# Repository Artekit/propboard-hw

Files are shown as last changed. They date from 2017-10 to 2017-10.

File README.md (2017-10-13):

# Artekit PropBoard Hardware

This repository contains hardware-related files for the [Artekit PropBoard](https://www.artekit.eu/products/devboards/propboard/).

(https://www.artekit.eu/products/devboards/propboard/)

## Documentation

* [Product page](https://www.artekit.eu/products/devboards/propboard/)
* [Manual & APIs](https://www.artekit.eu/doc/categories/propboard/)

## License

Released under the Creative Commons Attribution Share-Alike 3.0 License (http://creativecommons.org/licenses/by-sa/3.0)

Copyright (c) 2017 Artekit Labs.

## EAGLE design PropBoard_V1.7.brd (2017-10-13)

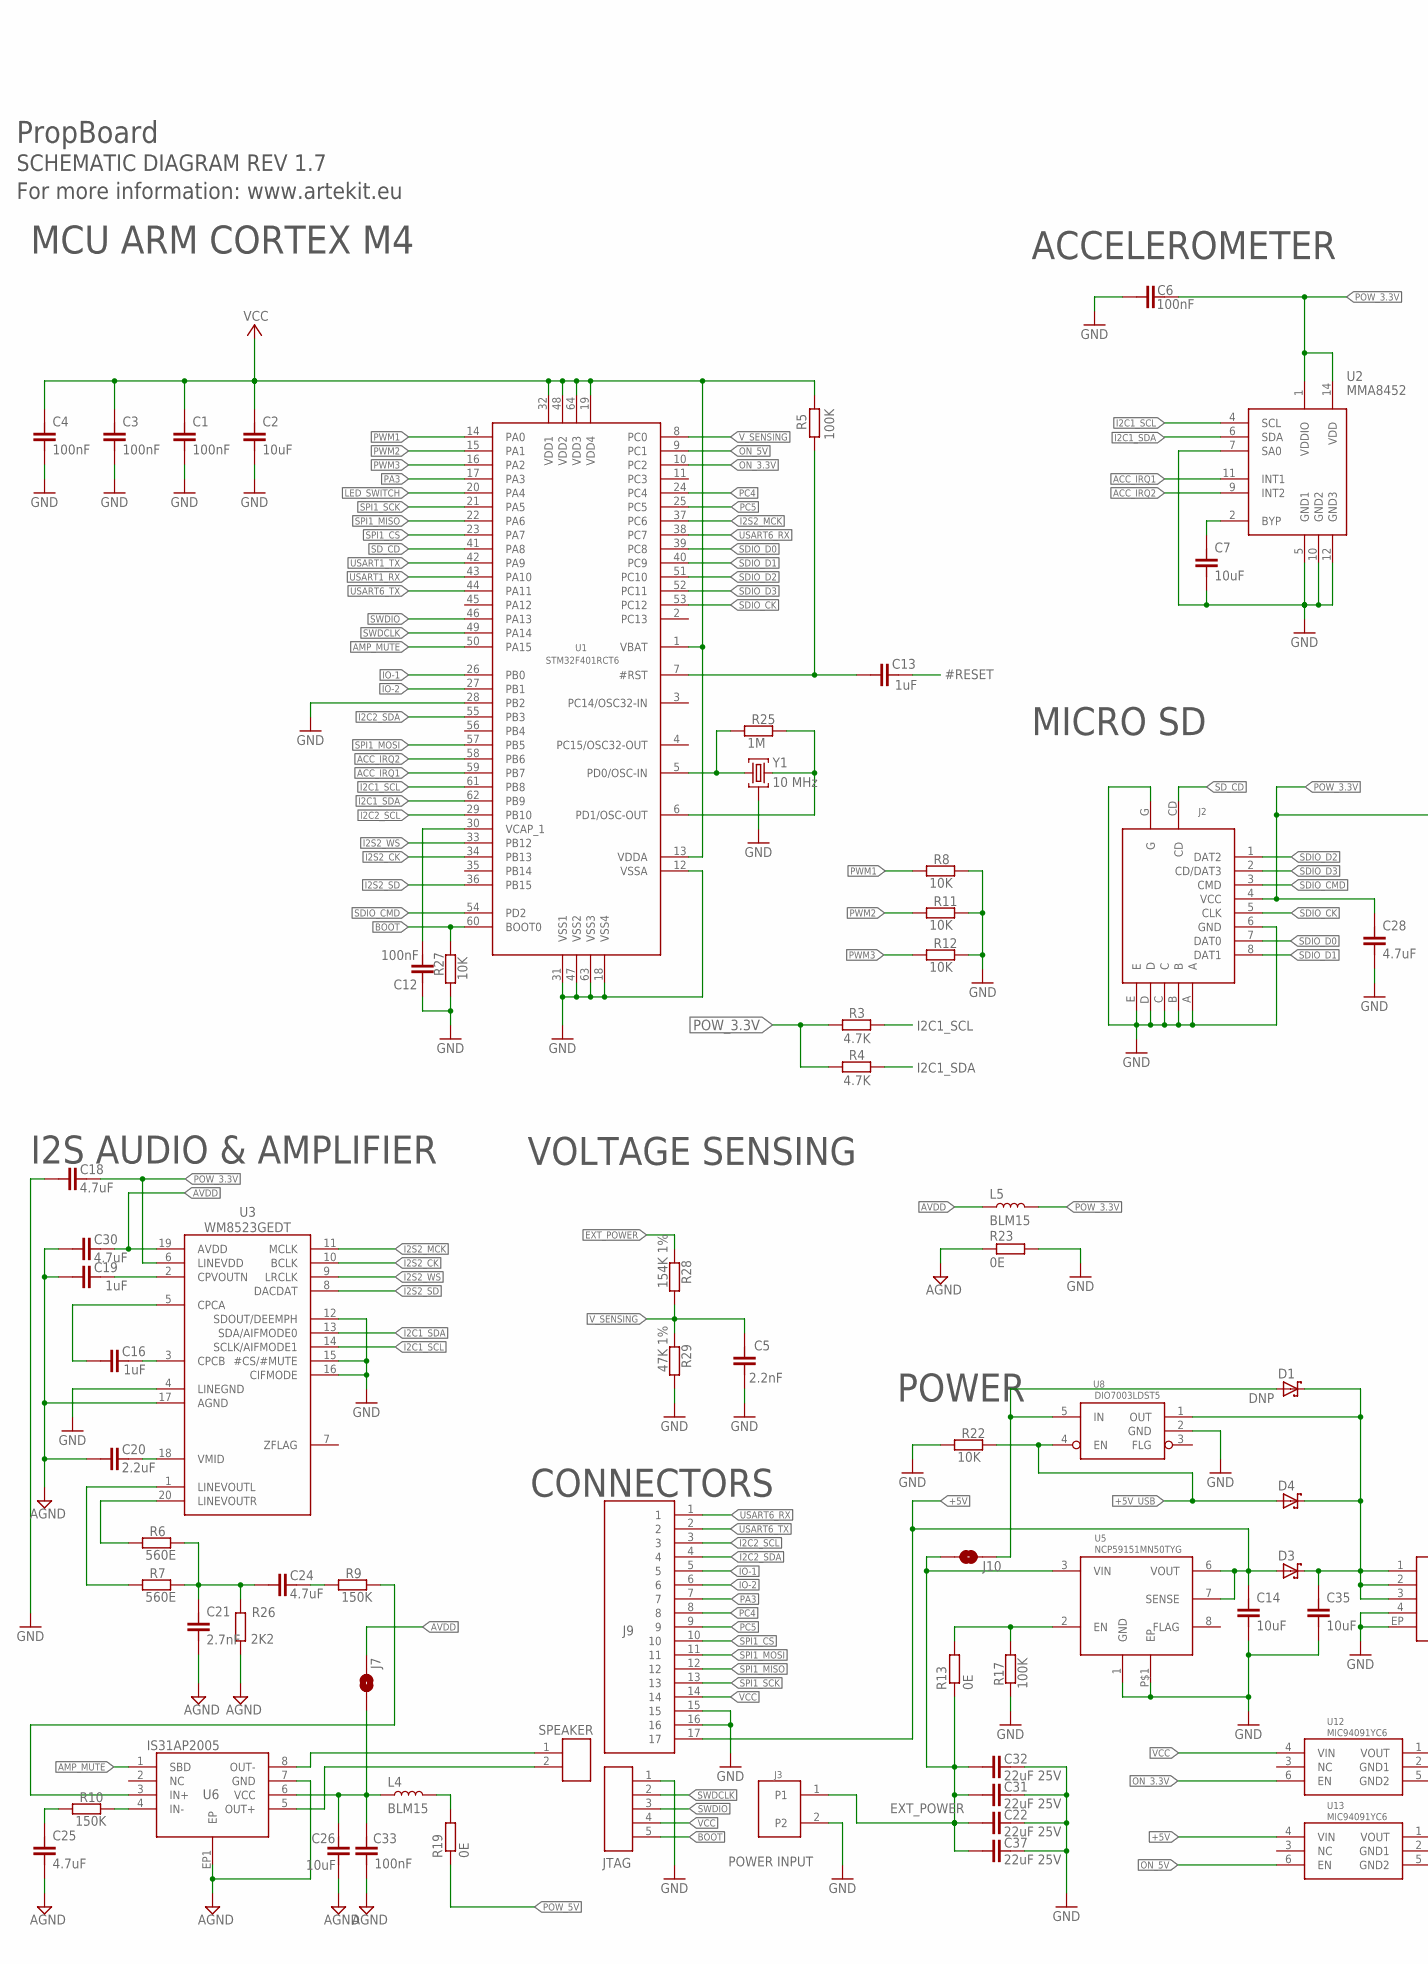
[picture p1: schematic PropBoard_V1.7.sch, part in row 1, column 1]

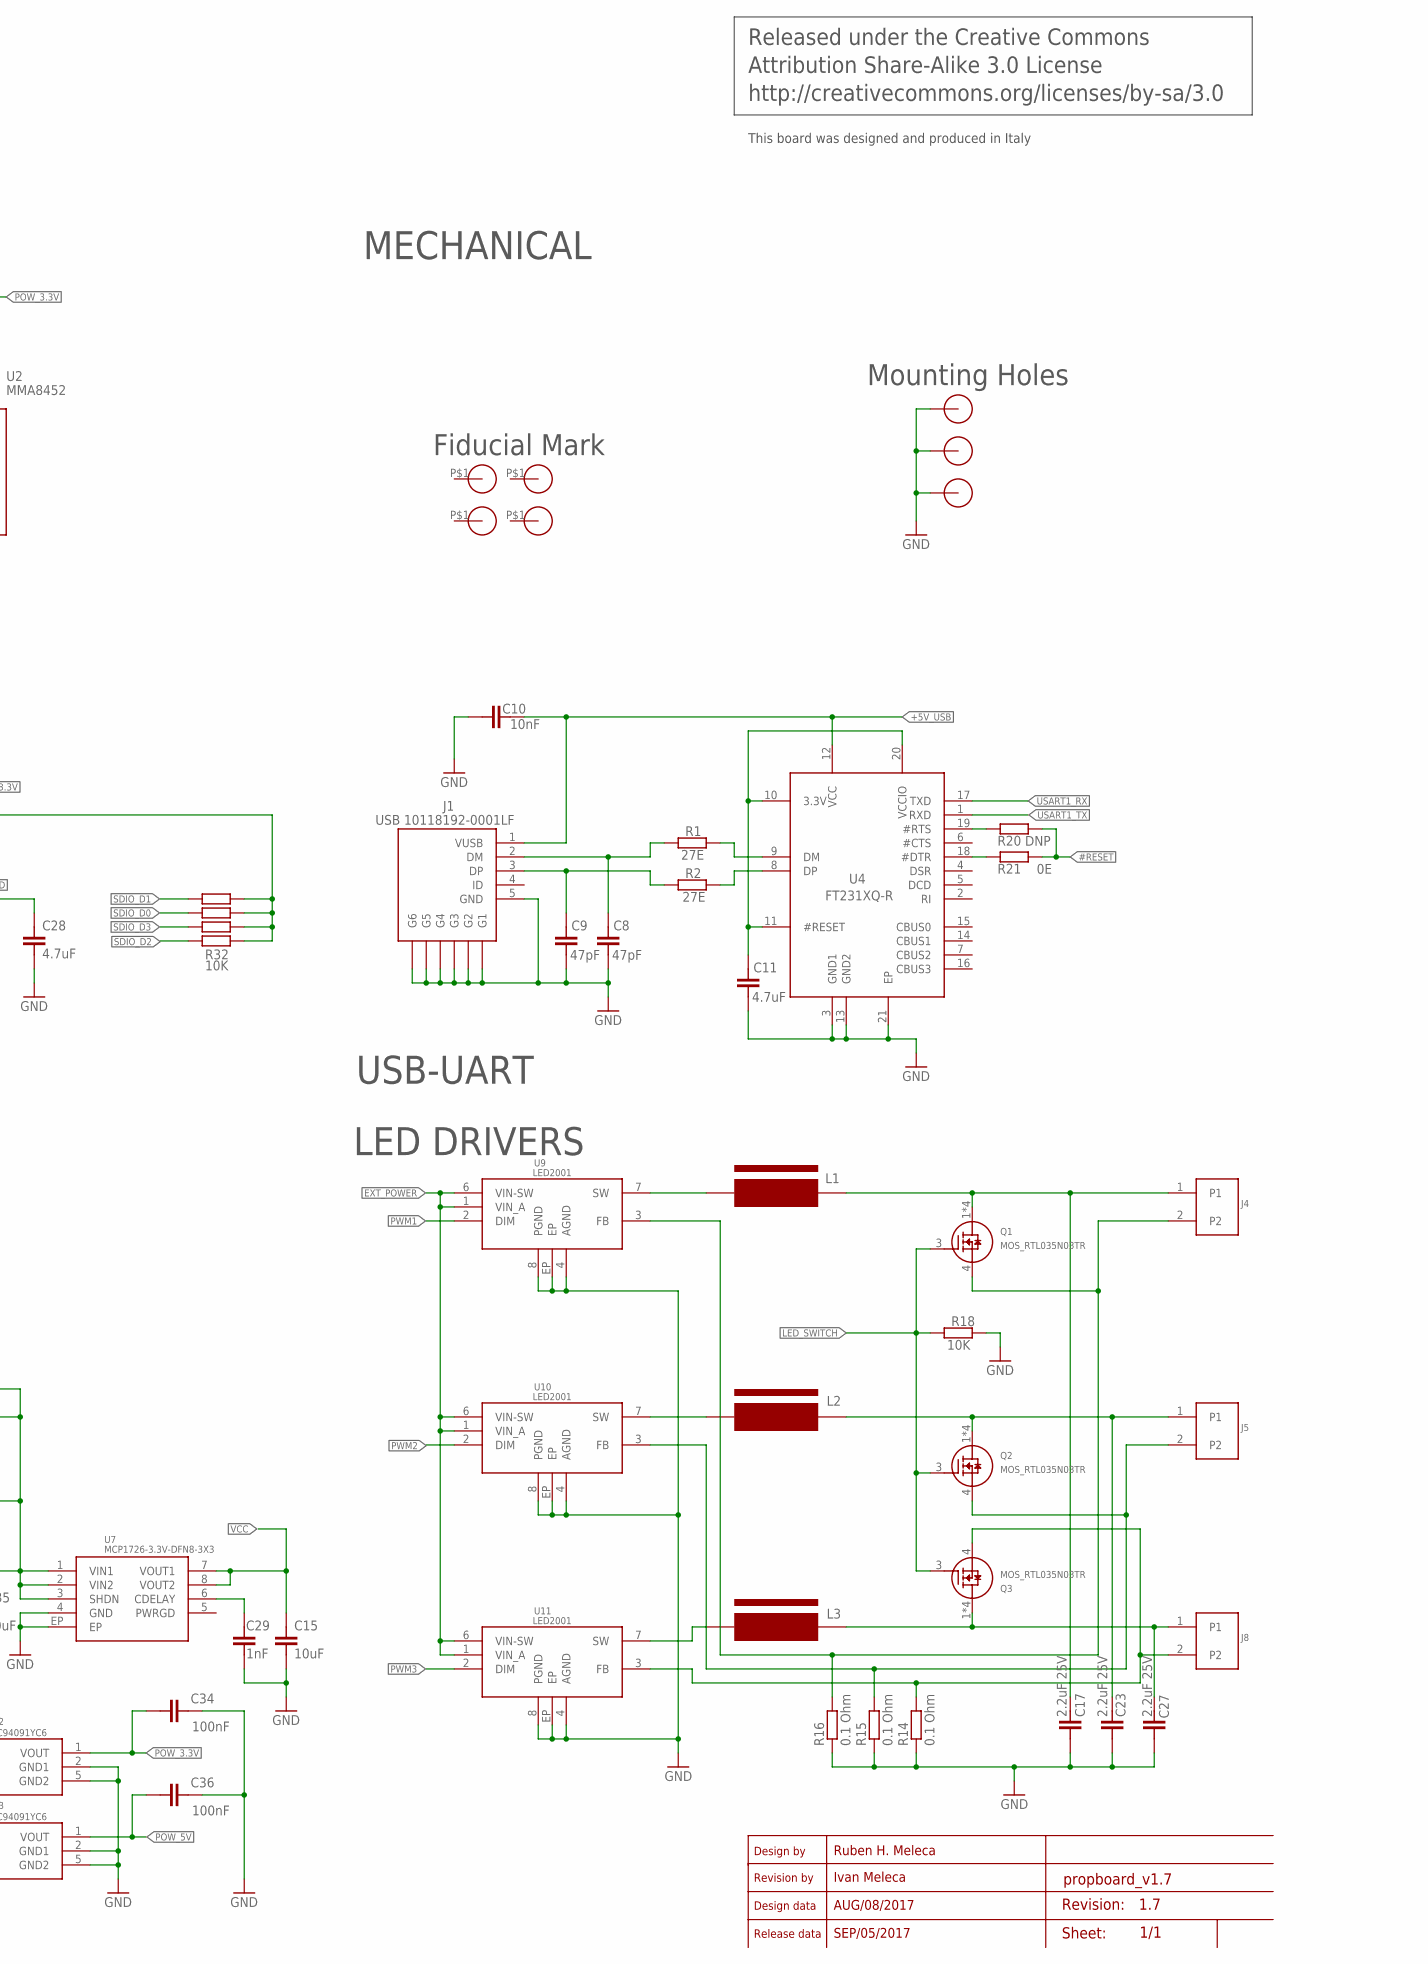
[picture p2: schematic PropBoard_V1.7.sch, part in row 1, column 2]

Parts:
C1, C3, C4, C6, C12, C33, C34, C36: 100nF; C0402
C2, C7, C14, C15, C26, C35: 10uF; C0402
C5: 2.2nF; C0402
C8, C9: 47pF; C0402
C10: 10nF; C0402
C11, C18, C24, C25, C28, C30: 4.7uF; C0402
C13, C19: 1uF; C0402
C16: 1uF; C0402-WIDE
C17, C23, C27: 2.2uF 25V; C0603
C20: 2.2uF; C0402
C21: 2.7nF; C0402
C22, C31, C32, C37: 22uF 25V; C0805
C29: 1nF; C0402
D1: DNP; SOD-323
D3, D4: BAT60; SOD-323
J1: USB 10118192-0001LF; CON-USB-MICRO-B-SMD
J2: MICRO-SD-CON-MOLEX-503182-0852
J3: PROP-POWER-PAD; 2-WAY-POWER-PAD
J4, J5, J8: PROP-LED-PAD; 2-WAY-POWER-PAD-SMALL
J6: CON-PH-1X02-P0.1"2MM; PIN-HEADER-1X02-P2MM
J7, J10: JUMPER-1-OPEN
J9: CON-PH-1X17-P0.1; PIN-HEADER-1X17-NODASH
L1, L2, L3: SRN6028-3R9M; IND-MURATA-DG6050-SERIES; MPN SRN6028-3R9M
L4, L5: BLM15; I0402; MPN BLM15AG102SN1
Q1, Q2, Q3: MOS_RTL035N03TR; SOT-363-6
R1, R2: 27E; R0402
R3, R4: 4.7K; R0402
R5, R17: 100K; R0402
R6, R7: 560E; R0402
R8, R11, R12, R18, R22, R27: 10K; R0402
R9, R10: 150K; R0402
R13, R19: 0E; R0603
R14, R15, R16: 0.1 Ohm; R0805
R20: DNP; R0402
R21: 0E; R0402
R23: 0E; R0402; MPN BLM15AG102SN1
R25: 1M; R0402
R26: 2K2; R0402
R28: 154K 1%; R0402
R29: 47K 1%; R0402
R32: 10K; RES-ARRAY-0603
U1: STM32F401RCT6; LQFP64-10X10-P0.50; MPN STM32F401RCT6
U2: MMA8452; QFN-COL-16-3X3-P0.50-MMA8452
U3: WM8523GEDT; TSSOP-20
U4: FT231XQ-R; QFN20-4X4-P0.50
U5: NCP59151MN50TYG; DFN8-4X4
U6: IS31AP2005; DFN-8-3X3MM-P0.65
U7: MCP1726-3.3V-DFN8-3X3; DFN8-3X3
U8: DIO7003LDST5; SOT23-5
U9, U10, U11: LED2001; VFQFPN-8
U12, U13: MIC94091YC6; SOT363-6
U$1: CON-PH-1X05-P0.1"; PIN-HEADER-1X05-NODASH
U$2, U$3, U$4: HOLE-2MM-METALIZED
U$5, U$6, U$8, U$9: FIDUTIAL_1.2MM
Y1: 10 MHz; RESONATOR-MURATA-CSTCE-SERIES

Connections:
#RESET: C13.2, R20.1, R21.1
+5V: C14.1, D3.A, J9.17, U5.6 (VOUT), U5.7 (SENSE), U13.4 (VIN)
+5V_USB: C10.2, D4.A, J1.1 (VUSB), R22.2, U4.12 (VCC), U8.4 (EN)
ACC_IRQ1: U1.59 (PB7), U2.11 (INT1)
ACC_IRQ2: U1.58 (PB6), U2.9 (INT2)
AGND: C19.1, C20.1, C21.2, C25.2, C26.2, C30.1, C33.2, R23.1, R26.1, U3.17 (AGND), U6.7 (GND), U6.EP1 (EP)
AMP_MUTE: U1.50 (PA15), U6.1 (SBD)
AVDD: C30.2, J7.2, L5.1, U3.19 (AVDD)
BOOT: R27.2, U1.60 (BOOT0), U$1.5
EXT_POWER: C22.1, C31.1, C32.1, C37.1, J3.1, J10.1, R13.1, R28.2, U5.3 (VIN), U9.1 (VIN_A), U9.6 (VIN-SW), U10.1 (VIN_A), U10.6 (VIN-SW), U11.1 (VIN_A), U11.6 (VIN-SW)
GND: C1.2, C2.2, C3.2, C4.2, C5.2, C6.1, C7.2, C8.1, C9.1, C10.1, C11.1, C12.2, C14.2, C15.2, C17.2, C18.1, C22.2, C23.2, C27.2, C28.2, C29.2, C31.2, C32.2, C34.2, C35.2, C36.2, C37.2, J1.5 (GND), J1.6 (G1), J1.7 (G2), J1.8 (G3), J1.9 (G4), J1.10 (G5), J1.11 (G6), J2.6 (GND), J2.A, J2.B, J2.C, J2.D, J2.E, J2.G, J3.2, J9.15, J9.16, R8.2, R11.2, R12.2, R14.1, R15.1, R16.1, R17.2, R18.2, R22.1, R23.2, R27.1, R29.1, U1.12 (VSSA), U1.18 (VSS4), U1.28 (PB2), U1.31 (VSS1), U1.47 (VSS2), U1.63 (VSS3), U2.5 (GND1), U2.7 (SA0), U2.10 (GND2), U2.12 (GND3), U3.4 (LINEGND), U3.12 (SDOUT/DEEMPH), U3.15 (#CS/#MUTE), U3.16 (CIFMODE), U4.3 (GND1), U4.13 (GND2), U4.21 (EP), U5.1 (GND), U5.P$1 (EP), U7.4 (GND), U7.EP, U8.2 (GND), U9.4 (AGND), U9.8 (PGND), U9.EP, U10.4 (AGND), U10.8 (PGND), U10.EP, U11.4 (AGND), U11.8 (PGND), U11.EP, U12.2 (GND1), U12.5 (GND2), U13.2 (GND1), U13.5 (GND2), U$1.1, U$2.1, U$3.1, U$4.1, Y1.2
I2C1_SCL: R3.1, U1.61 (PB8), U2.4 (SCL), U3.14 (SCLK/AIFMODE1)
I2C1_SDA: R4.1, U1.62 (PB9), U2.6 (SDA), U3.13 (SDA/AIFMODE0)
I2C2_SCL: J9.3, U1.29 (PB10)
I2C2_SDA: J9.4, U1.55 (PB3)
I2S2_CK: U1.34 (PB13), U3.10 (BCLK)
I2S2_MCK: U1.37 (PC6), U3.11 (MCLK)
I2S2_SD: U1.36 (PB15), U3.8 (DACDAT)
I2S2_WS: U1.33 (PB12), U3.9 (LRCLK)
IO-1: J9.5, U1.26 (PB0)
IO-2: J9.6, U1.27 (PB1)
LED_SWITCH: Q1.3 (G), Q2.3 (G), Q3.3 (G), R18.1, U1.20 (PA4)
unnamed: R1.2, U4.9 (DM)
unnamed: R2.2, U4.8 (DP)
unnamed: C8.2, J1.2 (DM), R1.1
unnamed: C9.2, J1.3 (DP), R2.1
unnamed: R10.2, U6.4 (IN-)
unnamed: C11.2, U4.10 (3.3V), U4.11 (#RESET), U4.20 (VCCIO)
unnamed: C7.1, U2.2 (BYP)
unnamed: L1.1, U9.7 (SW)
unnamed: C13.1, R5.1, U1.7 (#RST)
unnamed: R25.1, U1.5 (PD0/OSC-IN), Y1.1
unnamed: R25.2, U1.6 (PD1/OSC-OUT), Y1.3
unnamed: C16.2, U3.3 (CPCB)
unnamed: C17.1, J4.1, L1.2, Q1.1 (D), Q1.2 (D), Q1.5 (D), Q1.6 (D)
unnamed: C16.1, U3.5 (CPCA)
unnamed: C19.2, U3.2 (CPVOUTN)
unnamed: J4.2, Q1.4 (S), R16.2, U9.3 (FB)
unnamed: C20.2, U3.18 (VMID)
unnamed: R6.1, U3.20 (LINEVOUTR)
unnamed: R7.1, U3.1 (LINEVOUTL)
unnamed: R20.2, U4.19 (#RTS)
unnamed: C21.1, C24.1, R6.2, R7.2, R26.2
unnamed: R21.2, U4.18 (#DTR)
unnamed: C24.2, R9.1
unnamed: R9.2, U6.3 (IN+)
unnamed: L4.2, R19.2
unnamed: C25.1, R10.1
unnamed: J6.1, U6.8 (OUT-)
unnamed: J8.2, Q3.4 (S), R14.2, U11.3 (FB)
unnamed: C26.1, C33.1, J7.1, L4.1, U6.6 (VCC)
unnamed: J5.2, Q2.4 (S), R15.2, U10.3 (FB)
unnamed: C35.1, D1.C, D3.C, D4.C, U7.1 (VIN1), U7.2 (VIN2), U7.3 (SHDN), U8.1 (OUT)
unnamed: R13.2, R17.1, U5.2 (EN)
unnamed: C23.1, J5.1, L2.2, Q2.1 (D), Q2.2 (D), Q2.5 (D), Q2.6 (D)
unnamed: C27.1, J8.1, L3.2, Q3.1 (D), Q3.2 (D), Q3.5 (D), Q3.6 (D)
unnamed: L2.1, U10.7 (SW)
unnamed: L3.1, U11.7 (SW)
unnamed: J6.2, U6.5 (OUT+)
unnamed: D1.A, J10.2, U8.5 (IN)
unnamed: C29.1, U7.6 (CDELAY)
unnamed: C12.1, U1.30 (VCAP_1)
ON_3.3V: U1.10 (PC2), U12.6 (EN)
ON_5V: U1.9 (PC1), U13.6 (EN)
PA3: J9.7, U1.17 (PA3)
PC4: J9.8, U1.24 (PC4)
PC5: J9.9, U1.25 (PC5)
POW_3.3V: C6.2, C18.2, C28.1, C34.1, J2.4 (VCC), L5.2, R3.2, R4.2, R32.2, R32.4, R32.6, R32.8, U2.1 (VDDIO), U2.14 (VDD), U3.6 (LINEVDD), U12.1 (VOUT)
POW_5V: C36.1, R19.1, U13.1 (VOUT)
PWM1: R8.1, U1.14 (PA0), U9.2 (DIM)
PWM2: R11.1, U1.15 (PA1), U10.2 (DIM)
PWM3: R12.1, U1.16 (PA2), U11.2 (DIM)
SDIO_CK: J2.5 (CLK), U1.53 (PC12)
SDIO_CMD: J2.3 (CMD), U1.54 (PD2)
SDIO_D0: J2.7 (DAT0), R32.3, U1.39 (PC8)
SDIO_D1: J2.8 (DAT1), R32.1, U1.40 (PC9)
SDIO_D2: J2.1 (DAT2), R32.7, U1.51 (PC10)
SDIO_D3: J2.2 (CD/DAT3), R32.5, U1.52 (PC11)
SD_CD: J2.CD, U1.41 (PA8)
SPI1_CS: J9.10, U1.23 (PA7)
SPI1_MISO: J9.12, U1.22 (PA6)
SPI1_MOSI: J9.11, U1.57 (PB5)
SPI1_SCK: J9.13, U1.21 (PA5)
SWDCLK: U1.49 (PA14), U$1.2
SWDIO: U1.46 (PA13), U$1.3
USART1_RX: U1.43 (PA10), U4.17 (TXD)
USART1_TX: U1.42 (PA9), U4.1 (RXD)
USART6_RX: J9.1, U1.38 (PC7)
USART6_TX: J9.2, U1.44 (PA11)
VCC: C1.1, C2.1, C3.1, C4.1, C15.1, J9.14, R5.2, U1.1 (VBAT), U1.13 (VDDA), U1.19 (VDD4), U1.32 (VDD1), U1.48 (VDD2), U1.64 (VDD3), U7.7 (VOUT1), U7.8 (VOUT2), U12.4 (VIN), U$1.4
V_SENSING: C5.1, R28.1, R29.2, U1.8 (PC0)

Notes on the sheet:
POWER INPUT
JTAG
SPEAKER
POWER
CONNECTORS
LED DRIVERS
USB-UART
I2S AUDIO & AMPLIFIER
MCU ARM CORTEX M4
VOLTAGE SENSING
MICRO SD
ACCELEROMETER
MECHANICAL
PropBoard
SCHEMATIC DIAGRAM REV 1.7
For more information: www.artekit.eu
Released under the Creative Commons
Attribution Share-Alike 3.0 License
http://creativecommons.org/licenses/by-sa/3.0
This board was designed and produced in Italy
Fiducial Mark
Mounting Holes
Sheet:
Design by
Revision by
Design data
Release data
Revision:
Ruben H. Meleca
Ivan Meleca
AUG/08/2017
SEP/05/2017
1.7
DNP

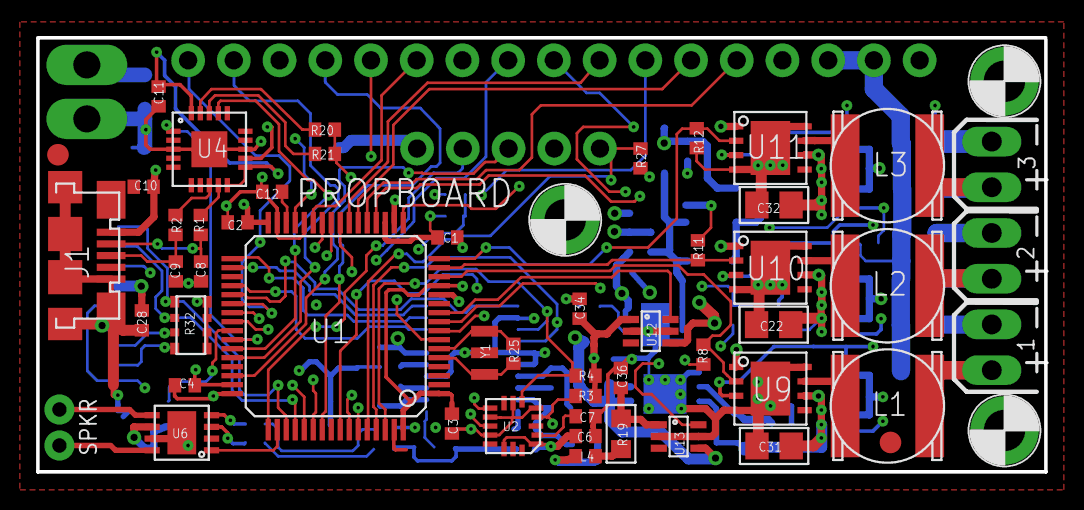
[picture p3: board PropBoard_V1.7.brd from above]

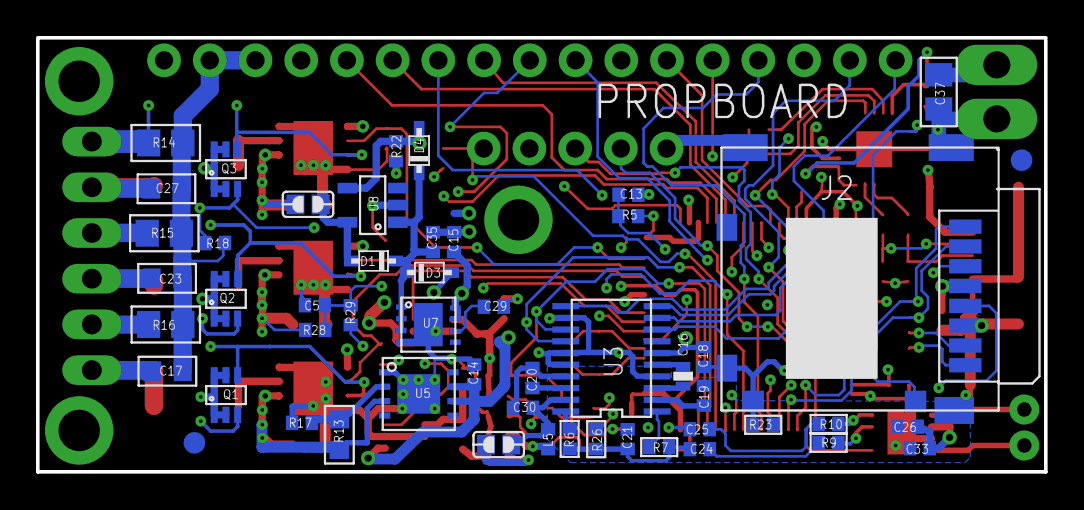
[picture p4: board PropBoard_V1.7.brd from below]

Board: 2 copper layers, 56.0 x 24.1 mm, 109 parts (52 on the bottom side), 91 nets.
